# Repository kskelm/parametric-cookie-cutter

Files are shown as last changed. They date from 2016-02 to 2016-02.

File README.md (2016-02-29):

# Parametric Cookie Cutter (PCC)
*** 

Contributors:
* Kevin Kelm triggur@gmail.com
* Gary Rechnitz

Parametric Cookie Cutter is licensed under a Creative Commons Attribution 4.0 International License.

This package contains code to turn DXF-based outlines into cookie cutters for 3D printers.

## Versions ##
* 1.0.0 -- first release
* 1.0.1 -- added filled imprints
* 1.0.2 -- made inner flanges an option and defaulted it to false
* 1.0.3 -- fiddled constants to be more realistic
* 1.0.4 -- more documentation, new experimentation = new constants

## Usage ##

Parametric Cookie Cutter (PCC) is intended to be used interactively by fiddling with global variables in cookie_cutter.scad via OpenSCAD.  It may work with the command line, but I have no idea.

PCC generates shapes with the following features:
* A cutting edge that defines the shape of the cookie.
* An imprint edge that defines the pattern stamped into the cookie.
* A flange that sticks out from the top of the cutting edges and also optionally extends toward the center a small distance.  This is for rigidity and to provide an easy surface to push on.
* Optional strips going in both directions to support unconnected edges and internal peninsulas.

The quality of the results depends on a lot of factors (your skill as a baker aside).  These include the complexity of the shape, its size, the quality of your print, whether you smooth your prints, and more.

PCC allows you to build your cutter and imprinter in the same piece, but it's often wise to separate them so the imprint is done afterwards.  The larger the surface area of the cutter/imprinter, the more the dough will stick to it.  And of course if it sticks to it, then your cookie comes out looking funny (but tastes the same!).  If you're up for the experiment, try it both ways.

There are several categories of tunable variables in this package.

### DXF files ###
PCC allows you to name up to two DXF files containing the outlines of the cookie cutter patterns:
* **cutFilename:**  This is the path to the DXF file containing the shape of the cookie cutter itself.  It's okay if curved edges have a low segment count; cookies are low resolution anyway.
* **imprintFilename:** This optional DXF file is used to create a shallower "imprint" patter, allowing features to be baked into the center.  In the included examples, the eyes and mouth of the smiley face and the trefoil of the radiation symbol are imprints.  If you don't want an imprint, set this value to an empty string.

OpenSCAD can import simple DXF files, but it can handle only a small subset of the kinds of geometry people commonly use in DXF files.  I have had no luck getting it to import anything with curves; they either come out as line segments or the file fails to load entirely.

The easiest way to handle this is to have your software output your shape to an EPS file and then convert that file to DXF format.  There are free online services like https://cloudconvert.com/eps-to-dxf to do this.  The resulting DXF file will probably work with PCC.

Note that when you see your shape in the 3D viewer, it will appear backwards; the design is flipped so the upper flange can be printed flat.

### Coordinates/Units ###
Now this is a hot mess.  A lot of people work in AutoCAD, which may be using inches, feet, millimeters, or light years.  In any case, DXF doesn't support units, so OpenSCAD has no way of knowing what the original intent was. As far as I know, most 3D printers think in millimeters, so that's my assumption in this package.

To compensate, I added a scaling variable so nobody has to go back to the original editor and go through the hassle of several format conversions. This scales only the DXF file contents, not the features of the flanges and such:
* **scaleFactor:** This is a multiplier used to mash around the geometry of the imported DXF files.  This will almost certainly be an iterative process to see if you like the size of your object in Cura or whatever you're using.

Your object is expected to be near the origin.  It must be a 2D path.  Shapes don't need to be closed. The work area is defined as about 1 meter square, specifically for the creation of support strips (see below).  1 meter is a hell of a cookie, but I'm not judging if you want it to be larger.  There's a constant in the file called **workDiameter** to declare this.

### Tuneables ###
+ ***Flanges***.  A flange is printed to strengthen the edges and provide a surface to press on to push the cutter into the dough.  It's a little thicker than the edges. It sticks out, and it can also optionally stick into the shape a little as well.  Sometimes playing with the flange sizes gives you the ability to skip the support strips, but it's a matter of balance and personal preference.  If you make your imprints filled (see below), you may not need a flange on them unless you need the flanges to hold things in place.  The flanges are controlled by the following variables:
  - **cutFlangeRadius:** This is the distance in mm that the flange sticks out from the cut edges.  It also sticks into the shape by a fraction of the distance  (default 7).
  - **imprintFlangeRadius:** This is the radius for imprint flanges (defaults to the value of *cutFlangeRadius*).
  - **innerFlange:** If this is set true, a flange about a third the size of the outer one will be generated aimed toward the inside of the shape.  This is nice for structural reasons, but it can also interfere with trying to push the dough out after cutting the cookie (default false).
 
+ ***Support strips.*** Some shapes have internal floating features (like the smiley face example) or wobbly thin features (like the pi example).  If you use imprints, you'll need to play close attention to this to make sure you have strips that support your internal unconnected edges.  PCC will generate strips as part of the flange, controlled by the following variables:
  - **numSupportStrips:** The number of strips to generate in both directions.  Set this to 0 if you don't want any.  Strips are centered along the origin.  Note that you can keep on incrementing this and see no result if you don't also decrease the spacing (described below).  This is necessary because I fould no convenient means to have OpenSCAD calculate the bounding box of the shape.
  - **supportStripWidth:** The width in mm of each strip (default 4)
  - **supportStripSpacing:** The number of mm between strips, center-to-center (default 50).
  
+ ***Cutting/Imprinting***. There are parameters to control how the edges are generated.  The variables are:
  - **fillImprints:** Set this to true if you want your imprints filled instead of being cutting edges.  If what you want is some mix of filled and not filled, you're going to have to do that yourself when you create the DXF by adding extra stuff inside the boundaries you want filled.  For instance if you wanted to fill in a circle, you could add additional concentric circles inside it and let the imprint blade thickness take care of actually filling the space.  If you set this to true, you may want to set the *imprintFlangeRadius* to zero unless you need it for support.
  - **cutDepth:** This is the depth in mm of the edge.  This is a little bit of a misnomer because it's actually the depth of the entire object, including the flange.  The cut depth limits the depth of the cookie that can be cut.  If you want more height to accommodate thicker dough, change this (default 9).
  - **imprintDepth:** Like *cutDepth*, but for the imprint edges (default 7).  Note that the result is affected by the depth of the cookie dough; If the dough is thinner than **cutDepth**, then the imprint depth will be less pronounced.
  - **bladeThickness:** This is the thickness in mm of the cutting and imprint blades (default 1.5).  If you make it too thin, not only will it lose structural integrity but it may also result in the blade being holly and getting dough stuck in it.

***Esoterica***.  The following variables are likely to be of no practical importance:
  - **workDiameter:** This is the area over which support strips are generated.  If your cookies are greater than 1 meter then I guess increase this value. This was only necessary because I couldn't get the OpenSCAD tricks to work that would let me calculate the bounding box of the DXF contents so as to constrain the size of the support strips automatically.
  
## Baking ##
I came into this completely naïve.  I'm an engineer, not a baker.  Cookies... dough... Pillsbury... easy, right?  My first attempt used peanut butter cookie dough from a tube and it made cookies that puff up like marshmallows, obliterating all details.  The smiley face looked like a bee sting victim.

Also my first attempts were way too deep; they were about 15mm deep on the cuts and 7mm deep on the imprints, stamped into dough about a half inch deep.  Also wrong.

Gary Rechnitz has included a recipe with some additional instructions.

## Development ##

Feel free to fork this in github and request pulls.

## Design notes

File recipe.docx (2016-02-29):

Sugar cookies for cutout and imprint (NOT gluten-free)

Copyright © 2016 Gary Rechnitz.

Licensed under a Creative Commons Attribution 4.0 International License.

This recipe makes cookies that are generally less sugary and more flour-based. This allows them to bake without rising and spreading, thereby preserving all your lovingly created cutter details.

2 ¾ cups all-purpose flour
½ cup cornstarch
¾ teaspoon baking powder
¼ teaspoon table salt
¾ cup unsalted butter, softened
½ cup Crisco or vegetable shortening

1 cup sugar
1 egg
2 t vanilla extract

Combine the flour, cornstarch, baking powder and salt and set aside.

With an electric mixer on medium speed, cream the butter, the Crisco or vegetable shortening and the sugar for 1 minute. It will be lighter in color.

Add the egg and vanilla and mix until just blended.

On low speed, add the flour mixture until just incorporated. The dough should be soft and smooth.

Divide the dough in half and shape it into 2 disks about 6 inches in diameter. Wrap them in plastic wrap and refrigerate until firm enough to roll without sticking, about an hour. Place each disk between two sheets of parchment paper. Roll them to 3/8 inch thickness and return them to the refrigerator to cool for 10 minutes. The thickness is important; the recipe still rises a bit, so the thicker the cookie, the less detail that will be preserved.

Pre-heat the oven to 350°. Line two baking sheets with parchment paper.

Doing only disk at a time, peel the top parchment paper off the rolled dough and invert it onto a well-floured board. Remove the remaining sheet of parchment paper. Sprinkle the dough with flour (plus rice flour if available). Flour the cutter. Press the cutter straight down and make sure it’s all the way through, and leave it in place. You should be able to pull away the surrounding dough. Remaining scraps can be re-used for the next batch.

Transfer the cutout still inside the cutter to the prepared baking sheet. It may be firm enough to just lift over, or you man need to use a floured dough scraper or spatula. Carefully poke the dough out of the cutter. Depending on the temperature of the dough, the amount of flour on the cutter, the quality of the print, and the complexity of the pattern, it may take some patience and poking.

Place the cutouts 1” apart. If you made your imprint object separately, use that now, pressing the floured imprinter gently into the surface.

Bake one sheet of cookies at a time for approximately 12 minutes or until just barely golden at the edges. Cool cookies on the baking sheet for an additional 3 minutes, then transfer them to a wire rack to cool.

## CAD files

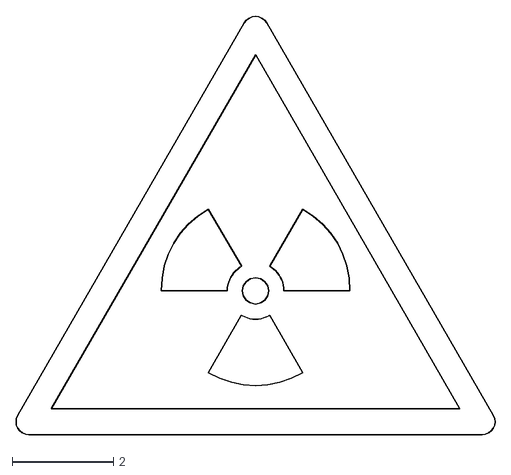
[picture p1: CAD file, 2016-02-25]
originals/radioactive.dxf
9.46 x 8.26

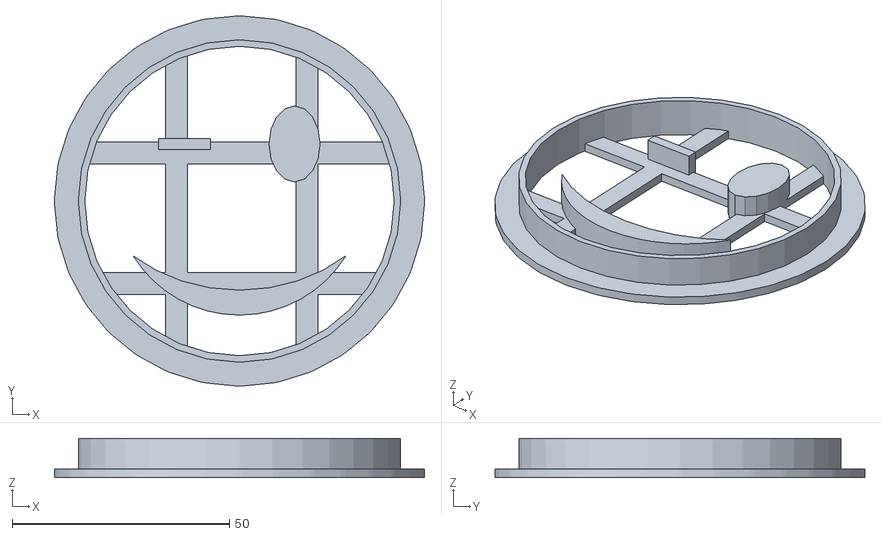
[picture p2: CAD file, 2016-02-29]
smiley_face.stl
85.1 x 85.1 x 9.00

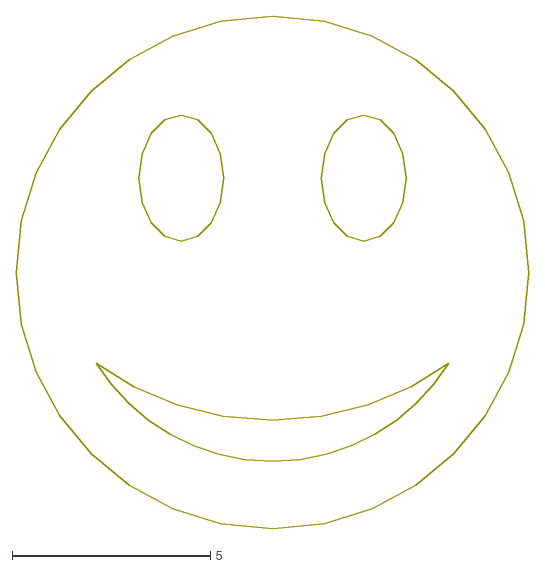
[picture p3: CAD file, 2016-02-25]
originals/smiley_face.dxf
12.9 x 12.9

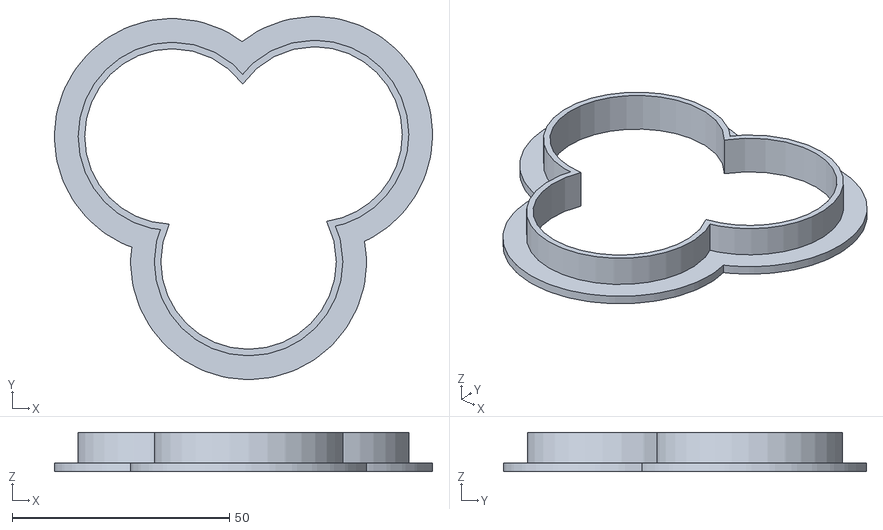
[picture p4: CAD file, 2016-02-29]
round_trefoil.stl
87.1 x 83.6 x 9.00

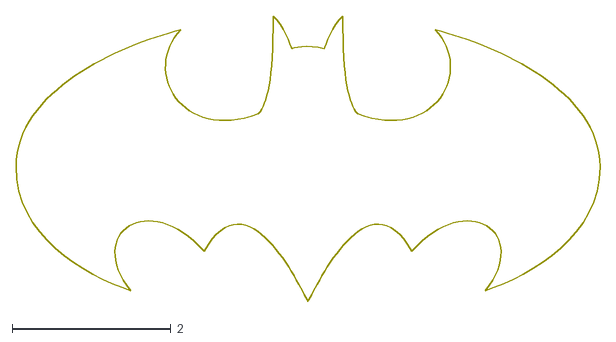
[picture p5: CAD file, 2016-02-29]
batman_imprint.dxf
7.35 x 3.59

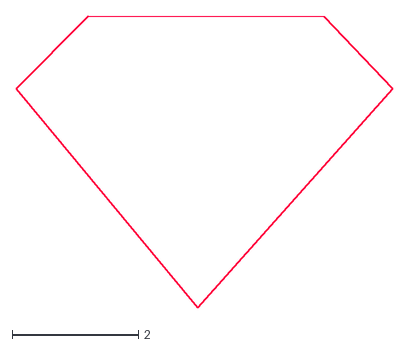
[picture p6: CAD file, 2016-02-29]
superman_cut.dxf
5.96 x 4.61

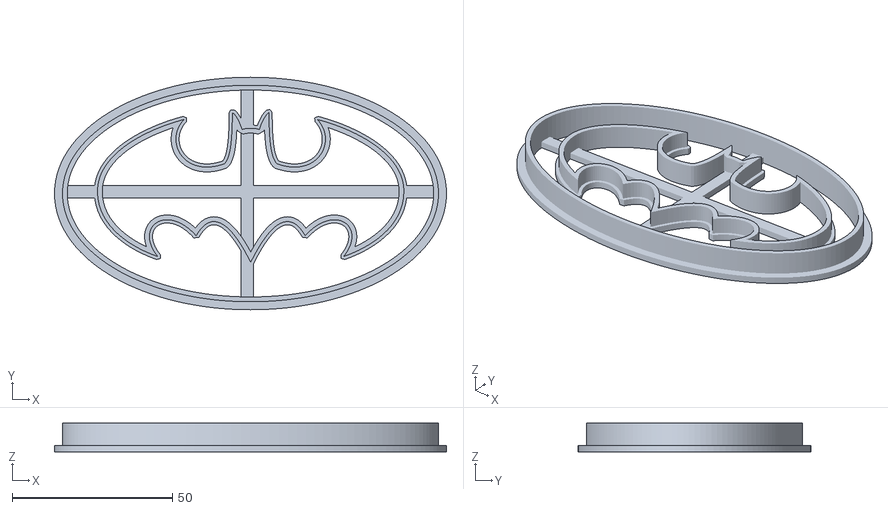
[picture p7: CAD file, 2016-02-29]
batman.stl
122.3 x 72.5 x 9.00

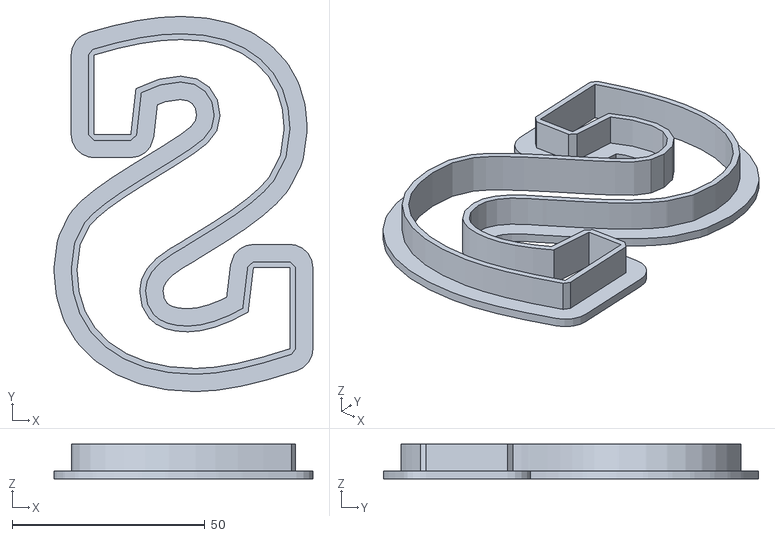
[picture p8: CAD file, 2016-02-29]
s.stl
67.2 x 97.3 x 9.00

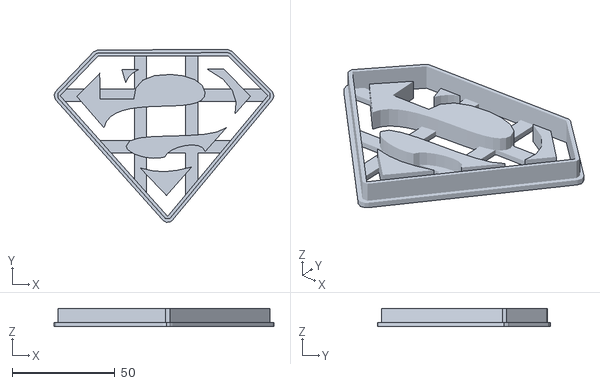
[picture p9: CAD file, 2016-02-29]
superman.stl
107.3 x 84.2 x 9.00

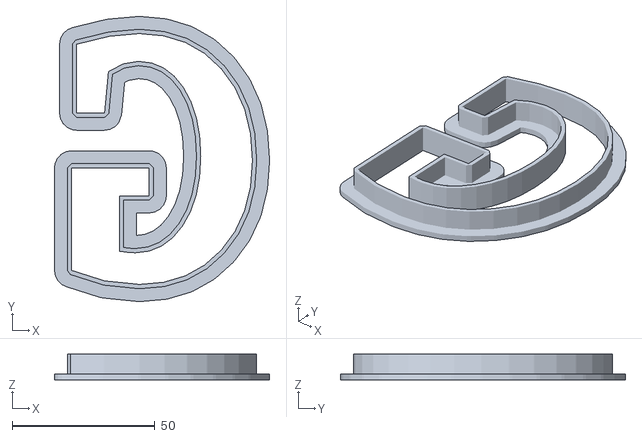
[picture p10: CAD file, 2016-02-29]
letter_g.stl
75.3 x 99.8 x 9.00

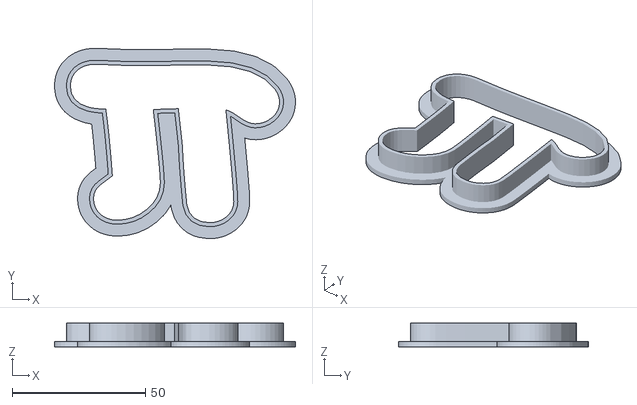
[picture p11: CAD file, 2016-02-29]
pi.stl
90.5 x 71.5 x 9.00

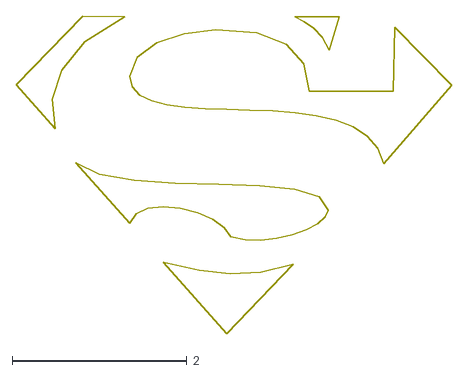
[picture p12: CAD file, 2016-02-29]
superman_imprint.dxf
4.98 x 3.63

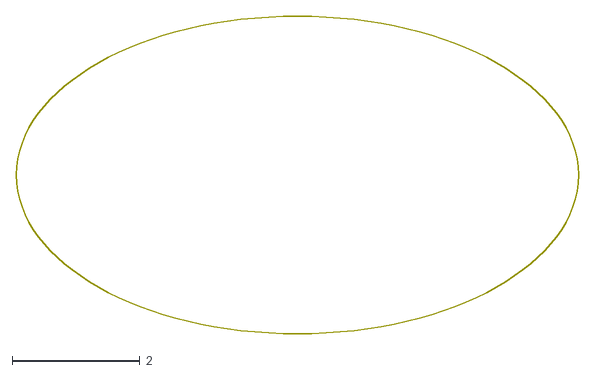
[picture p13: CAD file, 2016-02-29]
batman_cut.dxf
8.79 x 4.97

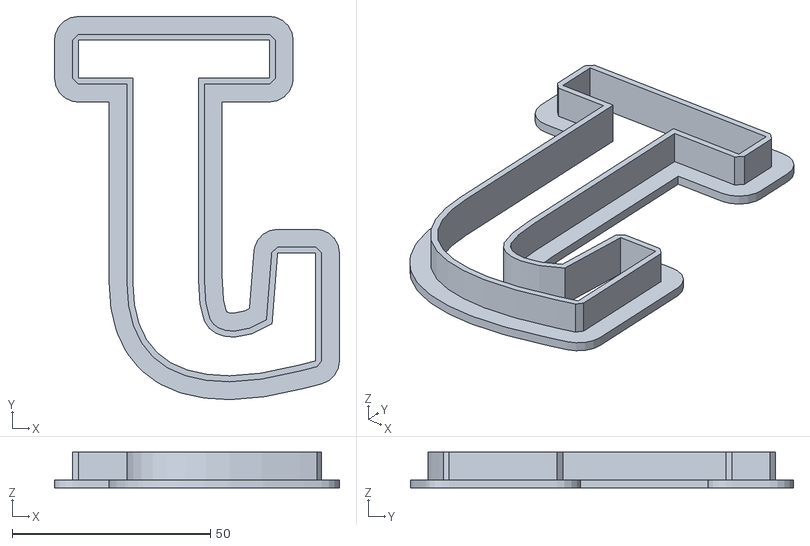
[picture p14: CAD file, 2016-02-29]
letter_j.stl
71.9 x 96.7 x 9.00

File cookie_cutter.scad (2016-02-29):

/*
 * Author: Kevin Kelm
 * Email: triggur@gmail.com
 * Date: 2015-02-21
 * Version: 1.0.1
 * License: Creative Commons CC-BY (Attribution)
 *
 */

// 1.0.0 -- first release
// 1.0.1 -- added filled imprints
// 1.0.2 -- made inner flanges an option and defaulted it to false
// 1.0.3 -- fiddled constants to be more realistic
// 1.0.4 -- more documentation, new experimentation = new constants

// NOTE: to play with the example files, scroll down to the
// little commented out blocks further down, and uncomment
// only the one you want to experiment with.
// In general, the most frequently changed constants are
// declared near the top of the file and they get more esoteric
// the further down you go.

// ====================================
// Tunable constants:

// This names the DXF file to be used as the cutter outline.
// OpenSCAD's implementation of DXF is missing a lot of
// fairly standard features, so pretty much everything needs
// to be a bunch of straight lines; splines and AutoCAD's
// polyline curves don't work correctly.  In my experience
// the best bet is to go from EPS to DXF; that seems to fix
// the problems I've had.  There's free online converters
// like https://cloudconvert.com/eps-to-dxf that can help
// with this.
// NOTE: In your 3D viewer, the shape will appear backwards
// because the print is upside down to accommodate the
// support flange.
cutFilename = "YOUR CUT FILE GOES HERE.dxf";

// Optionally, this second file can be used to generate
// a shallower "imprint" outline in the middle of the cookie.
// If you don't have such a file, comment this out.
imprintFilename = "YOUR IMPRINT FILE (IF ANY) GOES HERE.dxf";


// DXF has no inherent units. I'm also assuming all 
// printer software sees the world in millimeters.  If your
// software works differently or if your model's units are
// whacky, use this to scale it to mm.  An example
// would be something saved out of AutoCAD in inches.
scaleFactor = 5.5;

// Sometimes you don't want imprint edges, you want imprint
// areas.  Set this to true if you want the imprint regions
// filled as solid stamps.  Generally, you won't need to
// print imprint flanges if you're filling the imprints,
// unless you need the flange to reach support structures
// to hold them in place.
fillImprints = false;

// This defines how many support strips to create through
// the middle of the cutter base in both directions.  These
// strips provider structure to support any wobbly peninsulas
// or floating imprints in the middle of the cutter. Also,
// you'll need to adjust these parameters if your shape has
// islands that the default 50mm spacing doesn't hit.
numSupportStrips = 0;
// This is the width of a support strip.  All measurements are in mm.
supportStripWidth = 4;
// This is how far apart strips are, center-to-center.
supportStripSpacing = 50;


// This represents how deep the cutter edge goes (but actually
// this includes the flange, so it's really the depth of the whole
// object).
cutDepth = 9;
// This is how deep the imprint edge goes (ditto).
imprintDepth = 7;
// This is how thick the cut blades are.
bladeThickness = 1.5;

// This is how thick the flange base should be.
flangeThickness = 2;
// And this is the radius of flange coming out from
// the edge. A small flange extends inward as well.
cutFlangeRadius = 7;
imprintFlangeRadius = cutFlangeRadius;
// Whether flanges should extend inside the perimeters or not.
// It's nice for stability, but it can also interfere with getting
// the dough out once the cookie is cut.
innerFlange = false;

// This represents the work area. This only matters
// to the extents of the internal support structure.
// 1000 mm is one hell of a cookie, but I'm not
// judging. Make this bigger if you need to.
workDiameter = 1000;



// =================================================
// Examples.  Uncomment only one of these to get
// that example file.
// =================================================

// ======================
// smiley face settings
/*
cutFilename = "smiley_face_cut.dxf";
imprintFilename = "smiley_face_imprint.dxf";
scaleFactor = 5.5;
numSupportStrips = 2;
supportStripWidth = 5;
supportStripSpacing = 30;
fillImprints = true;
imprintFlangeRadius = 0;
*/

// ======================
// round trefoil settings
/*
cutFilename = "round_trefoil.dxf";
imprintFilename = "";
scaleFactor = 5;
numSupportStrips = 0;
*/


// ======================
// radiation settings
/*
cutFilename = "radioactive_cut.dxf";
imprintFilename = "radioactive_imprint.dxf";
scaleFactor = 9;
numSupportStrips = 0;
supportStripWidth = 4;
imprintFlangeRadius = 0;
cutFlangeRadius = 3.5;
fillImprints = true;
*/


// ======================
// pi settings
/*
cutFilename = "pi.dxf";
imprintFilename = "";
scaleFactor = 5;
numSupportStrips = 0;
cutFlangeRadius = 6;
*/

// ======================
// superman settings
/*
cutFilename = "superman_cut.dxf";
imprintFilename = "superman_imprint.dxf";
scaleFactor = 17;
numSupportStrips = 2;
supportStripWidth = 6;
supportStripSpacing = 25;
fillImprints = true;
cutFlangeRadius = 3;
imprintFlangeRadius = 0;
*/

// ======================
// batman settings
/*
cutFilename = "batman_cut.dxf";
imprintFilename = "batman_imprint.dxf";
scaleFactor = 13;
// if you set numSupportStrips to zero, then the imprint pattern will
// be created in the center without supports.  This can be an advantage
// when you have a complex shape and you don't trust it to come out of the
// cutter cleanly.  That way you use the oval cutter and then just press
// the bat imprint into it once that's done.  Another way to do this would
// be to run this script with the imprint file AS the cut file and it will
// still generate structure inside the imprint, but it will be separate.
// Yet another way to do this if there are floating pieces like in the smiley
// face would be to make the oval cut, and then do another with the
// cut and imprint files reversed so that the cut pattern becomes just a
// handle of sorts that still contains the imprint pieces, and the
// imprint sticks out further than the cut.
numSupportStrips = 1;
supportStripWidth = 4;
supportStripSpacing = 40;
fillImprints = false;
cutFlangeRadius = 4;
imprintFlangeRadius = 1;
*/

// ======================
// J settings
// (why J?  it's a grandkid's initial)
/*
cutFilename = "letter_j.dxf";
imprintFilename = "";
scaleFactor = 17;
numSupportStrips = 0;
supportStripWidth = 5;
supportStripSpacing = 10;
imprintDepth = 10;
cutFlangeRadius = 6;
*/

// ======================
// G settings
// (why G?  it's a grandkid's initial)
/*
cutFilename = "letter_g.dxf";
imprintFilename = "";
scaleFactor = 17;
numSupportStrips = 0;
supportStripWidth = 4;
supportStripSpacing = 70;
imprintDepth = 10;
cutFlangeRadius = 6;
*/

// ======================
// S settings
// (why S?  it's a grandkid's initial)
/*
cutFilename = "letter_s.dxf";
imprintFilename = "";
scaleFactor = 15.5;
numSupportStrips = 0;
supportStripWidth = 5;
supportStripSpacing = 10;
imprintDepth = 10;
cutFlangeRadius = 6;
*/

// =================================================
// =================================================

cookieCutter();

/*
 * Given a DXF file representing a cut outline and
 * an optional file representing an imprint outline,
 * generate a cookie cutter object.  If "numSupportStrips"
 * is non-zero, also generate a grid inside the shape
 * for strength and to hold internal pieces in the right
 * place.
 */
module cookieCutter() {
  
  // cut edges offset to the outside and imprint edges offset to the inside.
  shellAndFlange(cutFilename, cutDepth, false, cutFlangeRadius, false );
  if (imprintFilename) {
    shellAndFlange(imprintFilename, imprintDepth, true, imprintFlangeRadius, fillImprints );
  } // if

  // create a grid of strips to support internal structures that's
  // bounded on the outside by the cookie cutter shape.
  if (numSupportStrips) {
    intersection() {
      union() {
          
        // x-strips
        stripStartX = -supportStripSpacing / 2 * (numSupportStrips - 1) - supportStripWidth / 2;
        for (stripNum = [0: numSupportStrips - 1]) {
          translate([stripStartX + stripNum * supportStripSpacing, -workDiameter / 2, 0]) {
            cube([supportStripWidth, workDiameter, flangeThickness]);
          } // translate
        } // for
        
        // y-strips
        stripStartY = -supportStripSpacing / 2 * (numSupportStrips - 1) - supportStripWidth / 2;
        for (stripNum = [0: numSupportStrips - 1]) {
          translate([-workDiameter / 2, stripStartY + stripNum * supportStripSpacing, -0]) {
            cube([workDiameter, supportStripWidth, flangeThickness]);
          } // translate
        } // for

      } // union
      linear_extrude(height = flangeThickness) {
        shape( cutFilename );
      } // extrude
    } // difference 

  } // if
} // cookieCutter
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

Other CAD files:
radioactive.stl
radioactive_cut.dxf
radioactive_imprint.dxf
letter_g.dxf
letter_j.dxf
letter_s.dxf
pi.dxf
round_trefoil.dxf
smiley_face_cut.dxf
smiley_face_imprint.dxf

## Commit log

2016-02-25 Initial checkin
    [cookie_cutter.scad, pi.dxf, pi.stl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]
2016-02-26 Added filled imprints
    [cookie_cutter.scad]
2016-02-27 Added a setting whether to do inner flanges or not
    [cookie_cutter.scad, pi.stl, radioactive.stl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]
2016-02-29 better docs, new examples
    [batman.stl, batman_cut.dxf, batman_imprint.dxf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]
